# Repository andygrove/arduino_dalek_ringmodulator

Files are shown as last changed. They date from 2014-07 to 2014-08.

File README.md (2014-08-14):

Arduino Ring Modular a.k.a Dalek Voice Changer
==============================================

Arduino sketch for a digital ring modulator which mixes audio input with a sine wave to produce the familiar Dalek voice effect.

The code is tested on the Arduino Uno but can run with other boards such as the Mega (see comments in the sketch).

In addition to an Arduino Uno or Mega, you will need the following hardware components:

- SparkFun Electret Microphone Breakout (https://www.sparkfun.com/products/9964)
- 2 x 10uF electrolytic capacitors
- 2 x 220 ohm resistor for LEDs
- 2 x LED for dome lights
- 1 x 330 ohm resistor for low pass filter
- Optional 10K potentionmeter to adjust the sine wave frequency
- Audio jack
- Active speakers i.e. PC speakers with built in amplifier

The latest schematics image can be found in the repo or at this link:

https://github.com/andygrove/arduino_dalek_ringmodulator/blob/master/eagle_schematics.png

Please post any questions or comments to the following forum on the Project Dalek web site (requires a free account).

http://www.projectdalek.com/index.php?showtopic=9746

There is also more information available on my blog:

http://theotherandygrove.com/projects/dalek-voice-modulator/

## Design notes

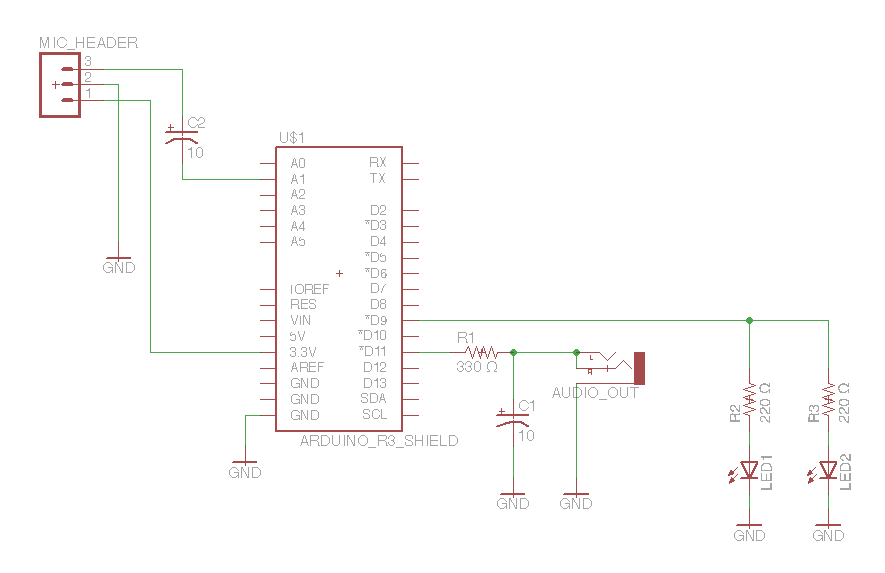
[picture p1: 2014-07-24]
eagle_schematics.png

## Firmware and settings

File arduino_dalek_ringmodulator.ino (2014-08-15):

/* Arduino Ring Modulator a.k.a Dalek Voice Changer
 *
 * Originally written by Andy Grove in September 2012.
 *
 * See the README.md for list of required electronics components and link to 
 * schematics diagram.
 * 
 * Takes mic/line input from analog pin 1 (A1) and mixes this signal with a
 * sine wave then plays the output to digital pin 10 or 11 depending on
 * the model of Arduino being used (10 on Mega 2560, 11 on most other boards).
 *
 * There is now an optional to connect a potentiometer to pin A0 to control the 
 * sine wave frequency.
 *
 * BE SURE TO UNCOMMENT THE CORRECT #defines FOR THE BOARD AND VOLTAGE YOU 
 * ARE USING! THEY ARE JUST BELOW THIS COMMENT BLOCK!
 *
 * Adapted from example code written by Martin Nawrath nawrath@khm.de
 * http://interface.khm.de/index.php/lab/experiments/arduino-realtime-audio-processing/
 *
 * This source file along with circuit diagrams is available from: 
 * https://github.com/andygrove/arduino_dalek_ringmodulator
 *
 * Please post any questions or comments to the following forum on the Project Dalek 
 * web site (requires a free account).
 * http://www.projectdalek.com/index.php?showtopic=9746
 *
 * To connect with me on Google+:
 * https://www.google.com/+AndyGrove73
 */

// IMPORTANT! MAKE SURE YOU CHOOSE THE CORRECT VALUES HERE, ESPECIALLY AREF! USING THE WRONG 
// VALUES COULD POTENTIONALLY DAMAGE YOUR ARDUINO!!

// if you have the mic connected to 3.3V (recommended since the 5V line is noisy) then you should 
// also connect AREF to 3.3V and uncomment the following line. If you have any Arduino pins connected 
// to 5V then make sure the following line is commented out.
#define AREF_EXTERNAL

// use these values if you are using an Arduino Uno R3 (pin 11 for audio output)
#define DDRB_NUM 3

// use these values if you are using an Arduino Mega 2560 R3 (pin 10 for audio output)
//#define DDRB_NUM 4

// pin to use for dome lights (LEDs)
#define DOME_LIGHT_PIN 9

// the dome light will come on when the audio signal goes above this number..a quiet signal 
// is around 127 so this number needs to be > 127 and < 255
#define DOME_LIGHT_THRESHOLD 180

// the code now supports some different effects modes, mostly to help with debugging
#define MODE_NO_EFFECT 1 // this mode passes the mic input directly to the audio out without modification
#define MODE_RING_MOD  2 // this is the default ring modulator mode where the mic input is mixed with a sine wave then written to audio out
#define MODE_SINE_WAVE 3 // this mode writes the sine wave directly to audio out
#define MODE_EXPERIMENTAL 4 // trying out new stuff here

// select which mode you want here
const int mode = MODE_RING_MOD;

// const double refclk=31372.549;  // =16MHz / 510
const double refclk=31376.6;      // measured

// constants for common frequencies ... calculation is: n = 31376/2/frequency
#define FREQUENCY_15_HZ 1045 // 
#define FREQUENCY_25_HZ  612 // actually 25.64 (NSD)
#define FREQUENCY_30_HZ  523 // Genesis

// for variable frequency controlled by a pot, comment out this next line
#define FIXED_FREQ  FREQUENCY_30_HZ

#ifdef FIXED_FREQ
#define NUM_SINE_WAVE_POINTS FIXED_FREQ
#else
#define NUM_SINE_WAVE_POINTS 1568 // refclk/2/10
#define MIN_INCREMENT 1 // 10 Hz
#define MAX_INCREMENT 5 // 50 Hz
#endif

// Audio Memory Array 8-Bit containing sine wave
byte sineWave[NUM_SINE_WAVE_POINTS];  

#define cbi(sfr, bit) (_SFR_BYTE(sfr) &= ~_BV(bit))
#define sbi(sfr, bit) (_SFR_BYTE(sfr) |= _BV(bit))

// we want to take samples on every nth interval
int intervalCounter = 0;

// interrupt variables accessed globally
volatile boolean f_sample;
volatile byte audioInput;
volatile byte pot;
volatile byte ibb;

byte audioOutput;

// how fast to step through the sine wave values... controlled by pot
int sineWaveIncrement = 1;

int sineWaveIndex = 0;

byte light;
int iw;
int iw1;
byte bb;

void setup()
{
  Serial.begin(9600);        // connect to the serial port
  Serial.println("Arduino Dalek Voice Changer");

  // generate sine wave values
  fill_sinewave();

  // set adc prescaler  to 64 for 19kHz sampling frequency
  cbi(ADCSRA, ADPS2);
  sbi(ADCSRA, ADPS1);
  sbi(ADCSRA, ADPS0);


  sbi(ADMUX,ADLAR);  // 8-Bit ADC in ADCH Register

#ifdef AREF_EXTERNAL
  // AREF set to external reference voltage (whatever is connected to the AREF pin)
  cbi(ADMUX,REFS0);
  cbi(ADMUX,REFS1);
#else
  // AREF set to VCC (5v on 5V Arduino boards, 3.3V on 3.3V boards)
  sbi(ADMUX,REFS0);
  cbi(ADMUX,REFS1);
#endif

  cbi(ADMUX,MUX0);   // Set Input Multiplexer to Channel 0
  cbi(ADMUX,MUX1);
  cbi(ADMUX,MUX2);
  cbi(ADMUX,MUX3);
  
  sbi(ADMUX,MUX0); // set multiplexer to channel 1

  // Timer2 PWM Mode set to fast PWM 
  cbi (TCCR2A, COM2A0);
  sbi (TCCR2A, COM2A1);
  sbi (TCCR2A, WGM20);
  sbi (TCCR2A, WGM21);

  cbi (TCCR2B, WGM22);

  // Timer2 Clock Prescaler to : 1 
  sbi (TCCR2B, CS20);
  cbi (TCCR2B, CS21);
  cbi (TCCR2B, CS22);

  // Timer2 PWM Port Enable
  sbi(DDRB,DDRB_NUM);              

  //cli();                         // disable interrupts to avoid distortion
  cbi (TIMSK0,TOIE0);              // disable Timer0 !!! delay is off now
  sbi (TIMSK2,TOIE2);              // enable Timer2 Interrupt

  // dome lights  
  pinMode(DOME_LIGHT_PIN, OUTPUT);
}

int counter = 0;
int nextSample = 0;

void loop()
{
  // wait for Sample Value from ADC
  // Cycle 15625 KHz = 64uSec 
  while (!f_sample) {     
  }                

  // reset the flag so that the next call to loop will wait until the 
  // interrupt code has obtained a new sample
  f_sample=false;

  // get next sample
  nextSample = audioInput;

  if (mode == MODE_NO_EFFECT) {
    // pass through input without any modification - good for initial testing!
    audioOutput = nextSample;
    
  } else if (mode == MODE_SINE_WAVE) {
    // get the next point from the sine wave data
    sineWaveIndex += sineWaveIncrement;
    if (sineWaveIndex >= NUM_SINE_WAVE_POINTS) {
      sineWaveIndex -= NUM_SINE_WAVE_POINTS;
    }
    // pass sine wave directly to audio out
    audioOutput = sineWave[sineWaveIndex];
  } else if (mode == MODE_RING_MOD) {
    
    // get the next point from the sine wave data
    sineWaveIndex += sineWaveIncrement;
    if (sineWaveIndex >= NUM_SINE_WAVE_POINTS) {
      sineWaveIndex -= NUM_SINE_WAVE_POINTS;
    }

    // get the next sinewave value and substract dc so it is in the range -127 .. +127
    iw = sineWave[sineWaveIndex] - 127;
    
    // get audiosignal and substract dc so it is in the range -127 .. +127
    iw1 = nextSample - 127;        
  
    // multiply sine and audio and rescale so still in range -127 .. +127
    iw  = iw * iw1 / 127;    
    
    // amplify (if necessary) then add 127 so back in range of 0 .. 255
    audioOutput = iw + 127;
  }
  
  // write to pin associated with timer 2 (10 or 11 depending on board)
  OCR2A=audioOutput;          

  // trigger dome lights if output signal above some threshold (hard-coded 
  // for now, but I'd like to make this variable based on a pot input so 
  // it can be adjusted easily)
  if (audioOutput > DOME_LIGHT_THRESHOLD && audioOutput > light) {
    light = audioOutput;
  }

  // fade away to simulate incandescent light bulb
  if (counter%10==0 && light>0) {
    light--;
  }

  // write new PWM signal to the LEDs once every 1000 times through this loop (so approximately 15 times per second)
  if (++counter == 1000) {
    counter = 0;
    analogWrite(9, light);
    
#ifndef FIXED_FREQ    
    // also update sine wave increment based on pot value
    // 1 through 10 translates to 10 Hz through 100 Hz in 10 Hz increments
    sineWaveIncrement = map(pot, 0, 255, MIN_INCREMENT, MAX_INCREMENT);
#endif
  }

} // loop

/**
 * Generates one complete sine wave into the 512 byte array.
 */
void fill_sinewave(){
  float pi = 3.141592;
  float dx ;
  float fd ;
  float fcnt;
  dx=2 * pi / NUM_SINE_WAVE_POINTS;   // fill the  byte bufferarry
  for (iw = 0; iw < NUM_SINE_WAVE_POINTS; iw++){      // with 50 periods sinewawe
    fd= 127*sin(fcnt);                // fundamental tone
    fcnt=fcnt+dx;                     // in the range of 0 to 2xpi  and 1/512 increments
    bb=127+fd;                        // add dc offset to sinewawe 
    sineWave[iw]=bb;                  // write value into array
    // uncomment this to see the sine wave numbers in the serial monitor
    /*
    Serial.print("Sine: ");
    Serial.println(bb);
    */
  }
}

/**
 * Timer2 Interrupt Service at 62.5 KHz 
 * runtime : xxxx microseconds
 */
ISR(TIMER2_OVF_vect) {
  
  intervalCounter++;

  if (intervalCounter>1) {
    if (intervalCounter==2) {
      // get pot reading to control frequency
      pot = ADCH;
      // set multiplexer to channel 1
      sbi(ADMUX,MUX0);               

    }
    else if (intervalCounter==3) {
      // take a sample every 4th time through, therefore audio is sampled in a rate of:  16Mhz / 256 / 4 = 15.625 KHz

      // reset the interval counter
      intervalCounter = 0;
      
      // get ADC channel 1 most significant 8 bits (0..255)
      audioInput = ADCH;

      // set multiplexer to channel 0
      cbi(ADMUX,MUX0);               
  
      // set flag so that loop() can continue and process the signal
      f_sample=true;
   
    }
    // short delay before the next conversion
    ibb++;
    ibb--;
    ibb++;
    ibb--;
    
    // start next conversion
    sbi(ADCSRA,ADSC);      
  }    
}

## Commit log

2012-09-26 add wiring diagrams
    [breadboard_diagram.fzz]
2014-07-23 bug fixes, better docs, removed redundant code
    [arduino_dalek_ringmodulator.ino]
2014-07-31 multiply input signal by 1.5 since it is 3.3V and arduino is expecting 5V
2014-07-31 fix bad comments, minor code improvement
    [arduino_dalek_ringmodulator.ino]
2014-08-09 can switch between variable or fixed frequency now
    [arduino_dalek_ringmodulator.ino]
2014-08-15 NUM_SINE_WAVE_POINTS was defined as 30 Hz when using FIXED_FREQ regardless of the selected frequency. Also improved AREF comment
    [arduino_dalek_ringmodulator.ino]
